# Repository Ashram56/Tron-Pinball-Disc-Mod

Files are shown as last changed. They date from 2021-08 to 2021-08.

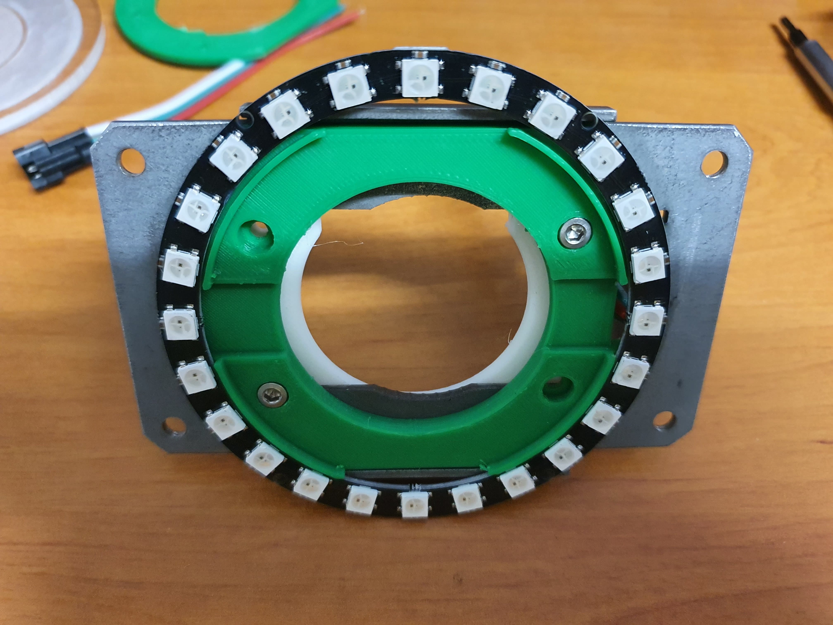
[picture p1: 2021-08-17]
130098325_203476967922881_1976459119455945771_n.jpg

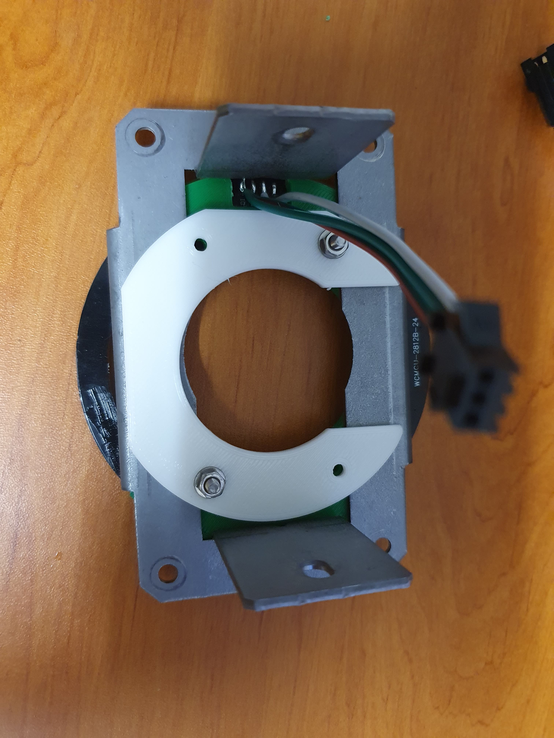
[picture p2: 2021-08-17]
130721082_776648902887255_6149550015372664479_n.jpg

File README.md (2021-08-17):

# Tron-Pinball-Disc-Mod
Tron pinball Disc mod

This is a repository for my Tron disc mod

Please see a video of the mod in action here: https://www.youtube.com/watch?v=_S456fI_wDA

Please pay attention to the licence: it is FREE to use, you can also build it and sell

HOWEVER: Please give credit if you plan to build and sell it, and if you make any modification (SW or HW), remember this is a GPL3 licence and all changes have to be published back, ideally as a fork of this document.

BOM cost is sub 10 dollars, aside of the control box

Requires a 24 led WS2812 ledring and M3 screws and bolts

Pay attention to the diameter, since otherwise it will not fit. Internal diameter is 35.5, external diameter is 43mm. Anything in between would fit, but if you change number of led you need to adjust the code

Solder wire (5V, ground, data in) Position led ring front side up, with IO pads above the opening. Plan for sufficient lenght to connect to wherever your control box is

Pictures of the assembly are provided on the github.

Please note that the plastic part I'm using on my unit is not the final one, I had to extend the part to add thickness to compensate for the ring added space

I recommend to use Pinduino (I designed my own board, but code should be portable), as on Tron Pinduino should be able to access the motor relays signals. If you use Pinduino, you will need a wire all the way to the backbox. I'm too busy to port the code over to Pinduino, somebody will surely manage to do it (and feed it back here :-) )

Control are essentially the two relays signals

Note that on my unit I replaced the black rubber ring with a transparent rubber ring to get better visibility on the light effects

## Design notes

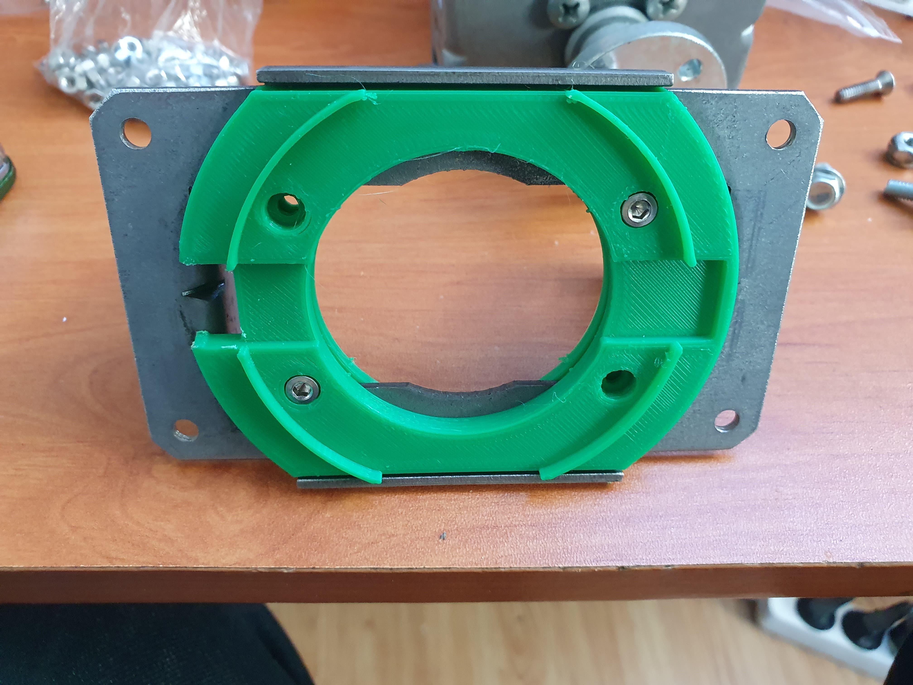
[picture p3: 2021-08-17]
130686720_2697444230570248_1112112996649709018_n.jpg

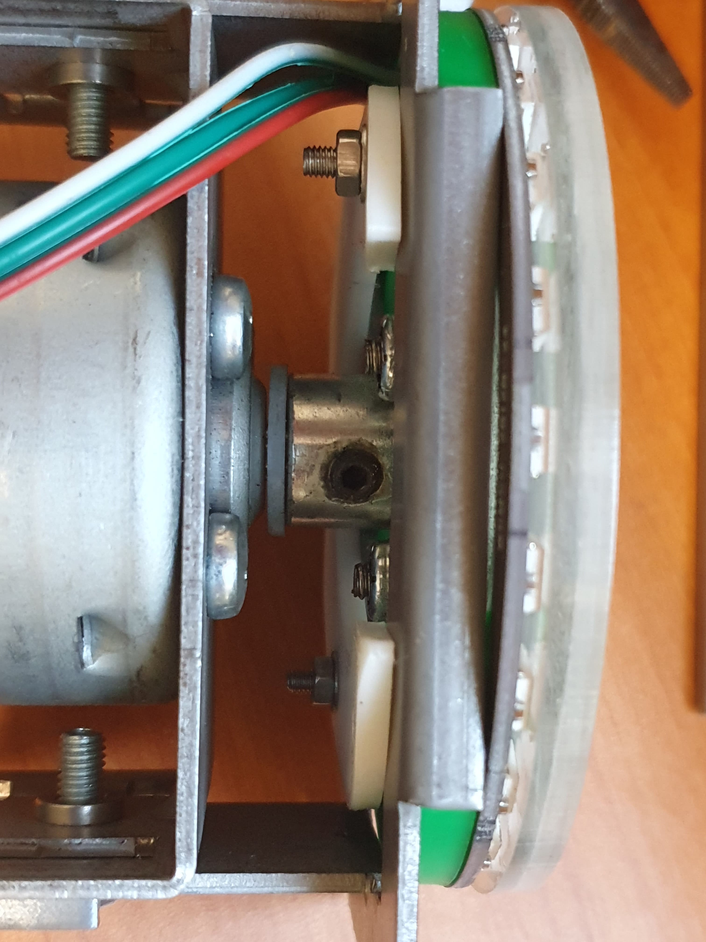
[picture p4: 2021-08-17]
130751362_224913709257178_9086256453583109368_n.jpg

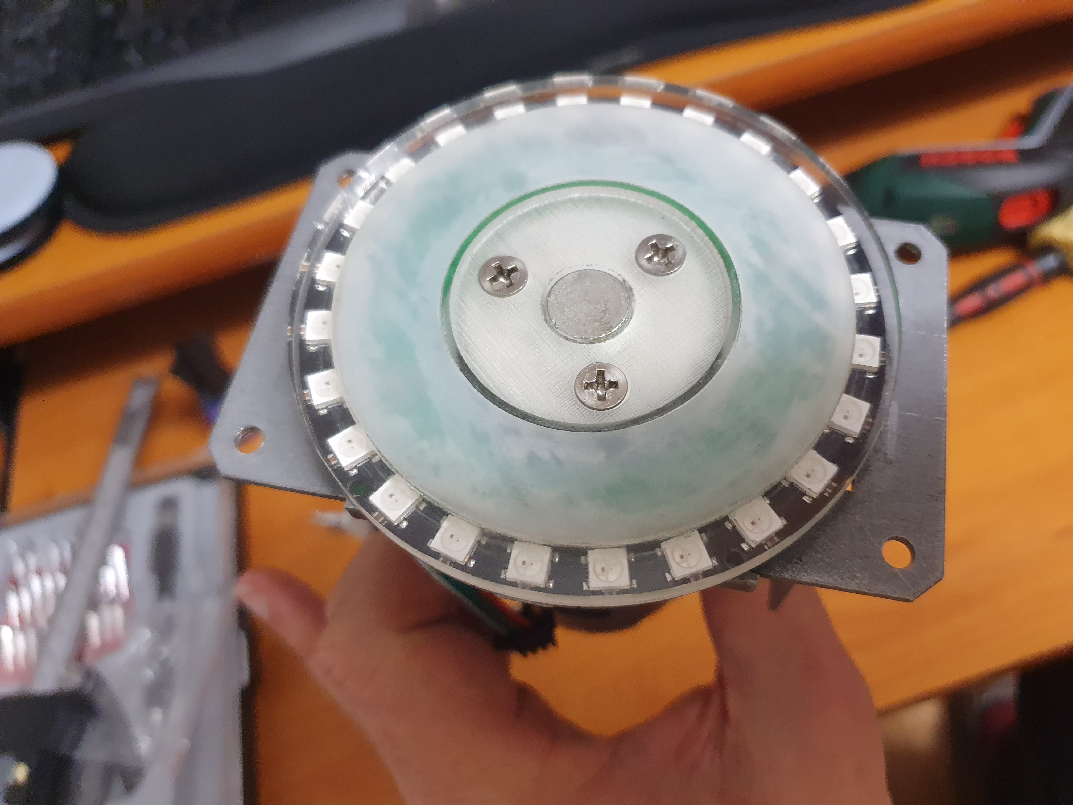
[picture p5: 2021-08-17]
130944293_2896820803971798_8030750590434811409_n.jpg

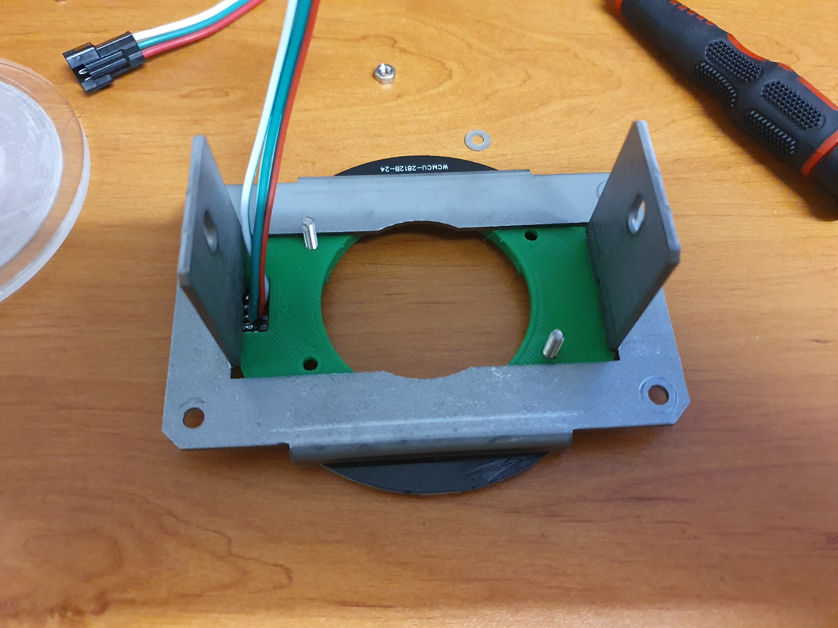
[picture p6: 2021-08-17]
130759941_2798942250319201_5424495222208433897_n.jpg

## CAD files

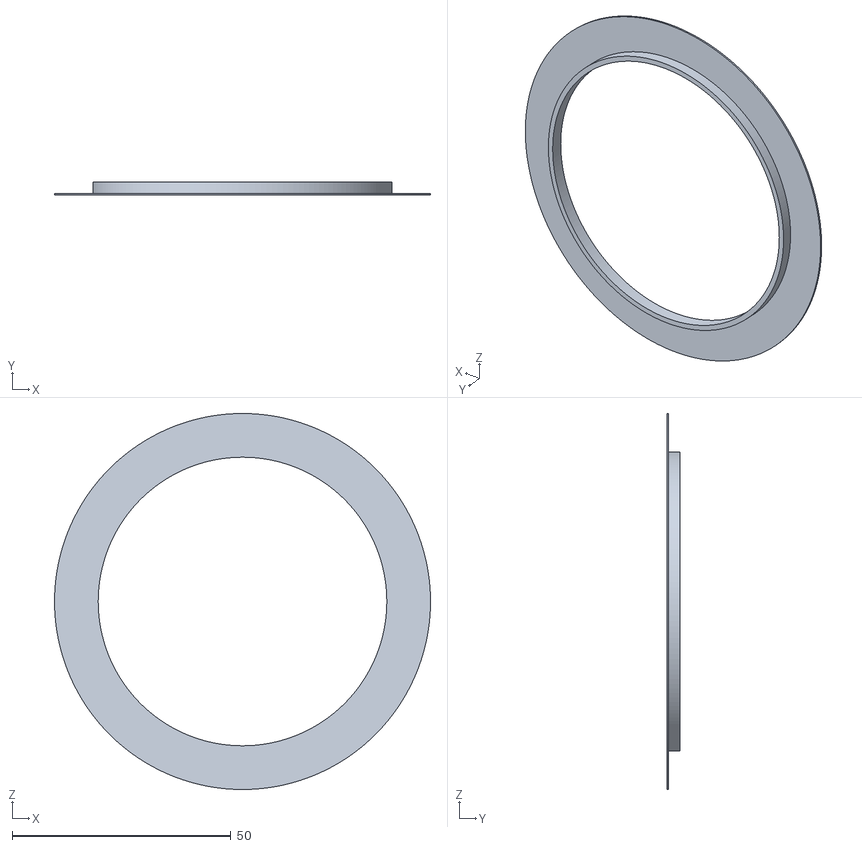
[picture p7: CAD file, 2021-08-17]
Anneau diffusant Tron.stl
86.0 x 3.00 x 86.0

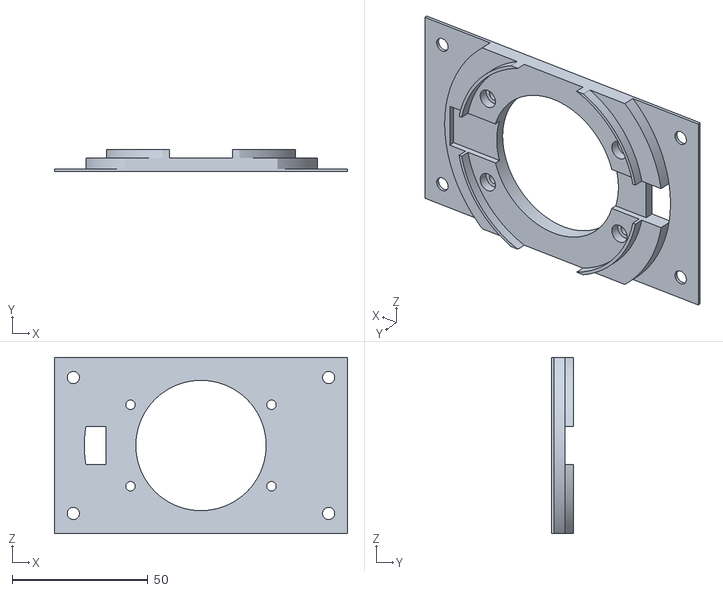
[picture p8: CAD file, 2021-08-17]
Support ring led Tron v10.stl
108.0 x 8.20 x 65.0

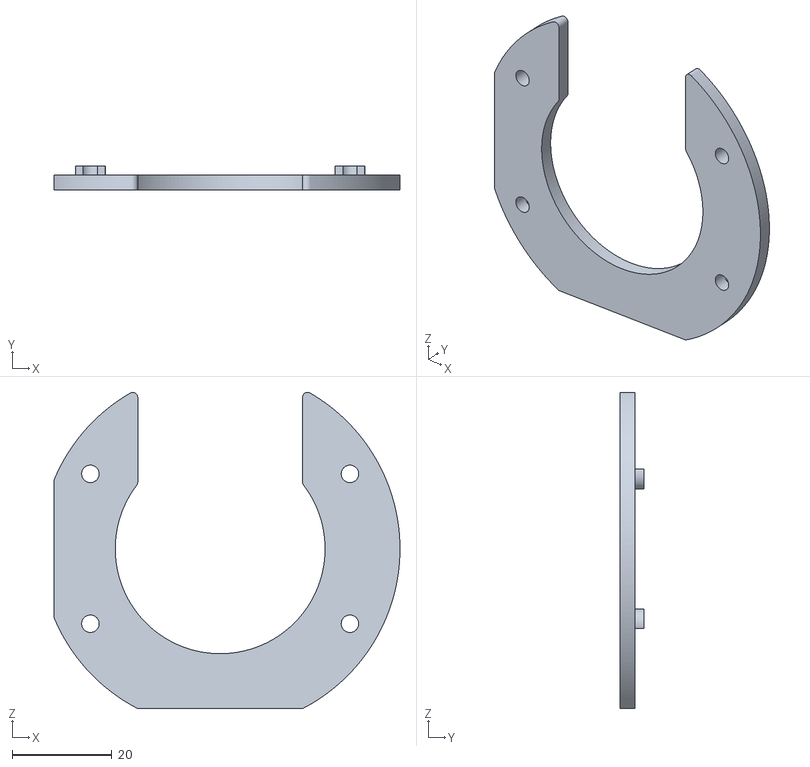
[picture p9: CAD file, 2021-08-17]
Anneau fixation support ring.stl
69.3 x 4.80 x 63.3

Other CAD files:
Support ring led Tron v11.f3d

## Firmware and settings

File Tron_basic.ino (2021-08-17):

#include <WS2812FX.h>

#define LED_PIN 14                       // 0 = GPIO0
#define LED_COUNT 24

#define DEFAULT_COLOR 0x0000FF
#define DEFAULT_BRIGHTNESS 255
#define DEFAULT_SPEED 750
#define DEFAULT_MODE FX_MODE_COMET

WS2812FX ws2812fx = WS2812FX(LED_COUNT, LED_PIN, NEO_GRB + NEO_KHZ800);

int inpin1 = 12;
int inpin2 = 13;
int val1 = 0;
int val2 = 0;
int MODE = 0; // 0 = idle, 1 = clockwise rotation, 2 = counter clockwise rotation
int PREVIOUS_MODE = 0;

void setup() {
  // put your setup code here, to run once:

Serial.begin(9600);
  delay(500);
  Serial.println("\n\nStarting...");

pinMode(inpin1,INPUT);
pinMode(inpin2,INPUT);

ws2812fx.init();


ws2812fx.setSegment(0,0,LED_COUNT-1,43,ORANGE,DEFAULT_SPEED*2,false);
ws2812fx.setSegment(1,0,LED_COUNT-1,43,ORANGE,DEFAULT_SPEED*2,true);

ws2812fx.setIdleSegment(2,0,LED_COUNT/2-1,DEFAULT_MODE,RED,DEFAULT_SPEED,REVERSE);
ws2812fx.setIdleSegment(3,LED_COUNT/2,LED_COUNT-1,DEFAULT_MODE,RED,DEFAULT_SPEED,REVERSE);

ws2812fx.setIdleSegment(4,0,LED_COUNT/2-1,DEFAULT_MODE,BLUE,DEFAULT_SPEED,FADE_SLOW);
ws2812fx.setIdleSegment(5,LED_COUNT/2,LED_COUNT-1,DEFAULT_MODE,BLUE,DEFAULT_SPEED,FADE_SLOW);

ws2812fx.setBrightness(DEFAULT_BRIGHTNESS);


//  ws2812fx.setMode(DEFAULT_MODE);
//  ws2812fx.setColor(DEFAULT_COLOR);
//  ws2812fx.setSpeed(DEFAULT_SPEED);
//  ws2812fx.setBrightness(DEFAULT_BRIGHTNESS);

ws2812fx.start();


}

void loop() {
  // put your main code here, to run repeatedly:

ws2812fx.service();

val1 = digitalRead(inpin1);
val2 = digitalRead(inpin2);

if (val1==0) MODE=0;
if (val1==1 && val2==0) MODE=1;
if (val1==1 && val2==1) MODE=2;


if (MODE==0)
		{
		if (ws2812fx.isActiveSegment(2))
			{
			ws2812fx.swapActiveSegment(2,0);
			ws2812fx.swapActiveSegment(3,1);
			Serial.println("MODE 0 From 2 to 0");
			}
		else
			if (ws2812fx.isActiveSegment(4))
				{
				ws2812fx.swapActiveSegment(4,0);
				ws2812fx.swapActiveSegment(5,1);
				Serial.println("MODE 0 From 4 to 0");
				}
		}

if (MODE==1)
		{
		if (ws2812fx.isActiveSegment(0))
			{
			ws2812fx.swapActiveSegment(0,2);
			ws2812fx.swapActiveSegment(1,3);
			Serial.println("MODE 1 From 0 to 2");
			}
		else
			if (ws2812fx.isActiveSegment(4))
				{
				ws2812fx.swapActiveSegment(4,2);
				ws2812fx.swapActiveSegment(5,3);
				Serial.println("MODE 1 From 4 to 2");
				}
		}

if (MODE==2)
		{
				if (ws2812fx.isActiveSegment(0))
					{
					ws2812fx.swapActiveSegment(0,4);
					ws2812fx.swapActiveSegment(1,5);
					Serial.println("MODE 2 From 0 to 4");
					}
				else
					if (ws2812fx.isActiveSegment(2))
						{
						ws2812fx.swapActiveSegment(2,4);
						ws2812fx.swapActiveSegment(3,5);
						Serial.println("MODE 2 From 2 to 4");
						}
				}


}
